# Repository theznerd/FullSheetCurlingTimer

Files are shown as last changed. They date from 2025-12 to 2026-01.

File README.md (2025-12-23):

# 🥌🥌🥌 Full Sheet Curling Timer 🥌🥌🥌

The purpose of this repository is to explore an inexpensive, ESP32-based, laser
trip timer for full sheet timing (4 lasers, 2 at each back line and 2 at each
hog line). Access to the times recorded by the timer is provided via a simple
web interface that connects to an ESP32 using the Web Bluetooth API. One ESP32
acts as a BLE Peripheral that hosts a custom GATT service for the timer, and all
four ESP32 devices will act as event detectors (laser trip detection) which
communicate the event data via ESP-NOW protocol to be picked up by the BLE
peripheral.

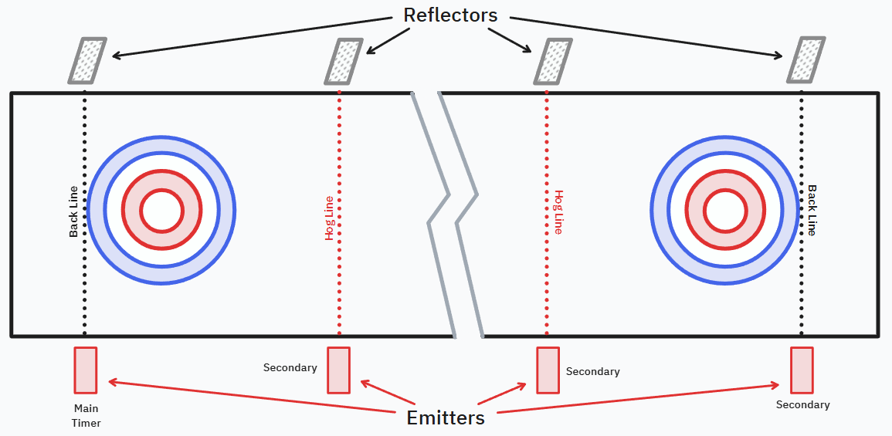
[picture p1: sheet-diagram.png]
Top-down view of sheet with emitters and reflectors


## License

This project is licensed under the Business Source License 1.1 (BUSL).
You may use it freely for noncommercial purposes.
For commercial use, please contact [nathan@z-nerd.com](mailto:nathan@z-nerd.com)
to obtain a commercial license.

## Goals

- **💸 Low-cost hardware**: inexpensive components (e.g., ESP32, laser modules)
  to keep single sheet cost under $150 (less when building for multiple sheets).
- **✅ Easy fabrication**: 3D-printable enclosure and PCBs for hobbyist skill
  level assembly (or schematics for breadboard assembly).
- **⏱️ Accurate timing**: millisecond-level accuracy for splits.
- **⚙️ Easy Setup and Use**: non-technical friendly setup and operation with
  guidance for setup and calibration provided in the web UI.
- **👀 Full sheet support**: support dual split timing (back line to hog line,
  and hog line to hog line) and bi-directional throws without moving hardware.
- **👨‍👩‍👧‍👦 Multi-viewer support**: allow multiple phones/tablets to connect and view
  timing data simultaneously.
- **🌐 Native App**: simple native app accessible from any modern platform
  with Bluetooth support - no cloud services, no complicated Wi-Fi setup for
  devices.

## Architecture (Multi-viewer)

### Roles and data flow

- **Main Timer and Laser Sensor - ESP32 = BLE Peripheral (GATT Server)**
  - Advertises a custom "Timer Service" so clients can discover it.
  - Has an assigned sheet ID (via dip switches) for identification.
  - Has an assigned placement ID (via dip switches) for sheet position.
  - Receives laser trip events from self and secondary timer devices (ESP-NOW).
  - Hosts characteristics for state + events.
  - Pushes timing updates using **notifications**.

- **Secondary Timer Devices - ESP32s = ESP-NOW Sender**
  - Has an assigned sheet ID (via dip switches) for identification.
  - Has an assigned placement ID (via dip switches) for sheet position.
  - Communicates laser trip events via ESP-NOW protocol.

- **Viewer (browser/web UI) = BLE Central (GATT Client)**
  - Scans for timer devices (filtered by name/service UUID).
  - Connects to **one** timer device at a time.
  - Provides diagnostics and setup UI.
  - Reads current timer state upon connection.
  - Subscribes to notifications to receive live updates.

This pattern supports multiple viewers concurrently: each viewer connects and
enables notifications independently.

### BLE Advertising For Viewer Discovery

To make it easy to pick the right timer when multiple devices are nearby, each
device should include clear identity in advertising:

- **Device name**: e.g., `CurlTimer Sheet 3`
- **Advertised Service UUID**: `Timer Service` (custom UUID)
- **Optional service/manufacturer data**: e.g., `sheetId`, `deviceId`,
  `firmwareVersion`

### GATT Service Model (proposed)

GATT is used for structured data exchange between the timer device and viewer.
GATT is well-suited for this use case due to its efficient notification
mechanism for real-time updates. Implementation details are discussed in the
[firmware design decisions](Firmware/design_decisions.md) document.

### Device-to-Device ESP-NOW Communication Model

ESP-NOW is the proposed protocol for communication between the laser sensors
and the main timer device. ESP-NOW was considered over BLE Advertising due to
better reliability and lower latency. Implementation details are discussed in
the [firmware design decisions](Firmware/design_decisions.md) document.

### Notes for future consideration

- WebKit has no support (actively opposes) for the Web Bluetooth API, and all
  iOS browsers are forced to use WebKit (with the exception of EU member
  states). Therefore, iOS support is not feasible with the current Web Bluetooth
  API limitations. Need to switch to a native app, which will bring added
  complexity. Looking at Avalonia for cross-platform native app development.
- It is possible to infer the direction of travel from the sequence of laser
  trip events, so that a stone passing the opposing back line does not cause a
  new timing event. However, this may be error-prone if stones are being thrown
  closely together in timing in opposite directions. Explicit direction setting
  from the viewer may be more reliable but requires user interaction which may
  be inconvenient or undesirable during practice.
- It may be useful to calculate the rock speed at each trip point and include
  that in the event data sent to viewers.
- **Timing accuracy note**: ESP-NOW retries/bursts improve delivery reliability
  but can add variable *arrival latency*. To keep recorded split times accurate,
  trip events should include a **sender-side capture timestamp** (taken at the
  instant the beam transition is detected), and the main timer should map that
  to its own clock using a lightweight beacon-based offset estimate.

## Wish List

- [ ] Apple WatchOS App for on-ice timing
- [ ] Garmin Connect IQ App for on-ice timing

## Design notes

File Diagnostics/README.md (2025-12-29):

# Diagnostic Tools

## Bluetooth LE

[BLE Scout](https://github.com/eriklins/BLE-Scout)

Works okay for basic scanning, but has a bug where the screen flashes and button
clicking is tempermental when scanning is active. Allowed me to see the
advertised names and services of the devices as well as connect and read the
GATT services and characteristics.

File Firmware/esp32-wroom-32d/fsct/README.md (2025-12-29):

# Full Sheet Curling Timer Firmware

Firmware for the Full Sheet Curling Timer project.

## Overview

This project implements embedded firmware for timing curling sheet events using
the an ESP32 microcontroller on a development board.

## Tested Hardware

- **ESP32-WROOM-32D Development Board**: Generic ESP32 dev board with the
    ESP32-WROOM-32D module.

## Build System

- **CMake**: Cross-platform build configuration
- **ESP-IDF**: Espressif IoT Development Framework

## Project Structure

```text
fsct/
├── main/              # Application source code
│   ├── adc/           # ADC driver implementation
│   ├── gatt/          # Bluetooth GATT service definitions
│   └── gpio/          # GPIO configuration
├── include/           # Header files
├── .devcontainer/     # Docker development environment
├── .vscode/           # VS Code configuration
└── build/             # Build artifacts (generated - excluded from repo)
```

## Getting Started

Use whatever you want - I don't care. I'm using VSCode with the ESP-IDF
extension, and I've installed v5.5.1 of the ESP-IDF toolkit. I don't use any of
the python scripts directly - I point an click in the ESP-IDF explorer to build,
flash, and monitor.

### Prerequisites

- ESP-IDF toolkit (v5.5.1 tested)

### Development Setup

Use the included Dev Container:

```bash
docker-compose up -d
```

Or configure manually with ESP-IDF.

### Building

```bash
idf.py build
```

### Flashing

```bash
idf.py flash
```

## Configuration

Edit `sdkconfig` or use the menuconfig tool:

```bash
idf.py menuconfig
```

## Version

See `version.txt` for current firmware version.

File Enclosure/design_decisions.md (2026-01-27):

# Enclosure Design Decisions

This document outlines the design decisions made for the enclosure of the trip
sensor for the project. The enclosure is designed to house the laser emitter,
phototransistor receiver, and associated component electronics providing
protection and proper alignment for accurate operation.

## Design Considerations

- **Durability**: The enclosure must be robust enough to withstand the
  environment of a curling sheet, including potential impacts and moisture.
- **Alignment**: The design must ensure precise alignment of the laser and
  phototransistor for accurate detection.
- **Ease of Assembly**: The enclosure should be easy to assemble and disassemble
  for maintenance and adjustments (e.g. where soldering is required, only use
  through-hole components).
- **Accuracy**: The enclosure must minimize external light interference to
  ensure reliable operation of the phototransistor (e.g. light tunneling).

## Current Needs Before Design

- [x] **PCB Design**: Finalize the PCB design to determine exact mounting points
  and dimensions for the enclosure.
- [x] **Component Dimensions**: Verify the dimensions of all components for
  accurate enclosure design.

## Current Notes from Field Tests

- Might better to put battery on top. Laser is a touch high of the midpoint
  of the stone.
  - Still considering this change which would allow for an adjustable base. The
    adjustable base would allow for fine tuning the height and angle of the
    laser, especially if a sheet is not level.
- ~~Laser alignment is very tempermental. Recommend decreasing tunnel diameter and hot gluing after aligned.~~
  - ~~Laser alignment is tempermental, but decreasing tunnel diameter did not yield
    better results (it forced the laser to be pointed possiby off axis without a
    way to adjust). Going back to a larger tunnel diameter and using hot glue to
    fix the laser in place after alignment.~~
  - Laser alignment is still an issue. Going to flip the laser module to the
    bottom of the enclosure, and then add a small ball joint mount to allow for
    fine tuning the laser angle when placing on the ice.

## Involved Components

### Laser Diode Module

The laser diode module used is a standard 650nm red laser module, with an 6mm OD
housing that includes a small notch in the middle for placement. A small circuit
board is attached to the back of the laser module that includes a resistor for
current limiting and a positive and ground wire.

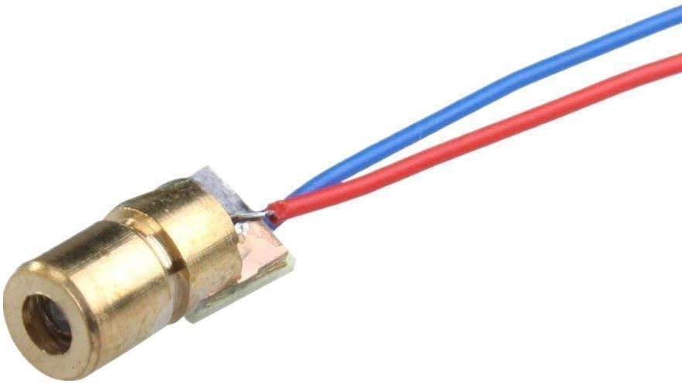
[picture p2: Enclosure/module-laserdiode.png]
Laser Diode Module


> NOTE: The reflector design was initially based on retroreflective tape, but
> this was found to be unreliable at distances beyond 1-2 meters. The design has
> been updated to use small bicycle retroreflectors for improved reliability.
> Still need to field test this change - especially with bright overhead
> lighting and reflective ice surfaces. An initial test of some rectangular
> reflectors was unreliable at 3-4 meters, but a standard bicycle reflector
> performed much more reliably.

### Main PCB Module

The main PCB module houses the main circuitry for the project. The PCB is
designed to fit within the enclosure and provide connections for ESP32 dev
board, power, laser, and phototransistor. The PCB is also designed to align the
phototransistor with the enclosure opening for optimal light detection and ease
of alignment. A 5-position DIP switch is included on the PCB for sheet and
placement ID selection, but does need to be externally accessible as the values
are not changed frequently.

\#\#\# No Photo Available Yet

### Piezo Buzzer Module

The piezo buzzer module is used to provide audio feedback for user interactions
such as power on/off and timing events. The buzzer is mounted on the main PCB
and positioned within the enclosure to allow sound to escape effectively. The
buzzer is an active type, meaning it includes an internal oscillator and only
requires a DC voltage to operate.

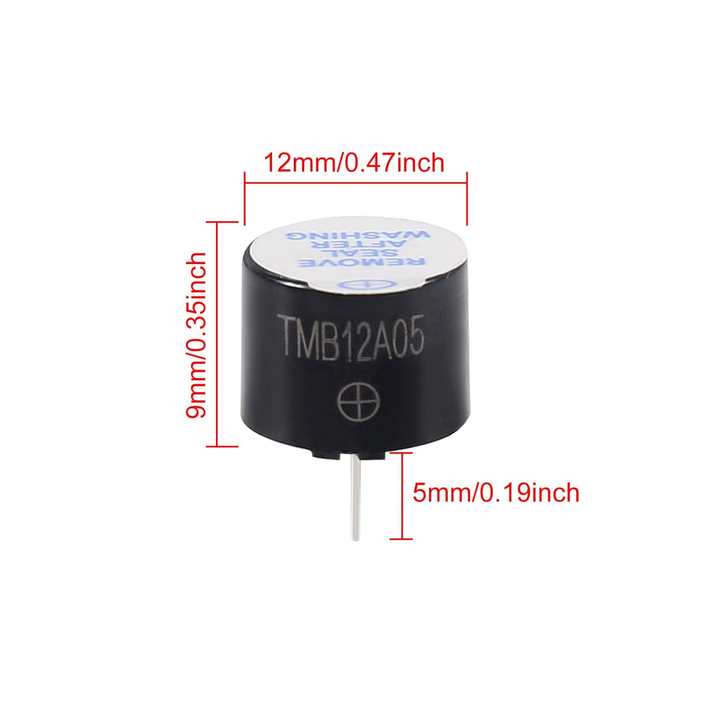
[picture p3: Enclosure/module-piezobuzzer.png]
Piezo Buzzer Module


### TP4056 Battery Charger Module with 5V Step-Up

The TP4056 battery charger module is used to charge the 18650 Li-ion battery. It
is mounted separately from the main PCB to allow for use of a development board
instead of integrating the charger and associated SMD components into the main
PCB (keeping the project hobbyist friendly). It has a USB-C connector for easy
charging. The module also includes LED indicators for charging status. It has an
integrated step-up converter to provide a regulated 5V output for the ESP32 dev
board and other components.

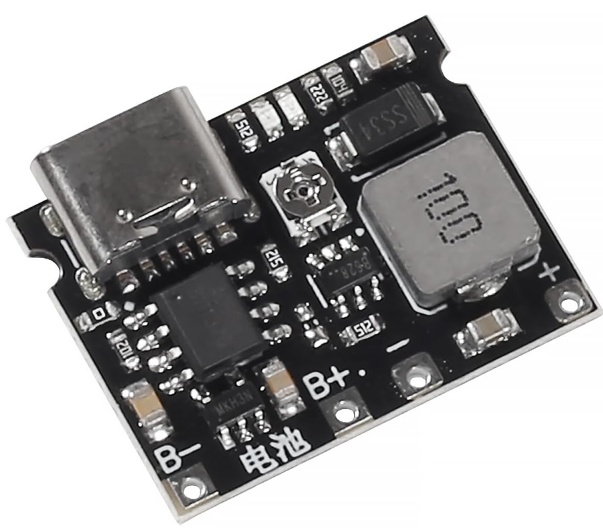
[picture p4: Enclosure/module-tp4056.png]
TP4056 Battery Charger Module


### 18650 Battery Holder

The 18650 battery holder is used to securely hold the battery within the
enclosure. It includes leads for easy connection to the main PCB.

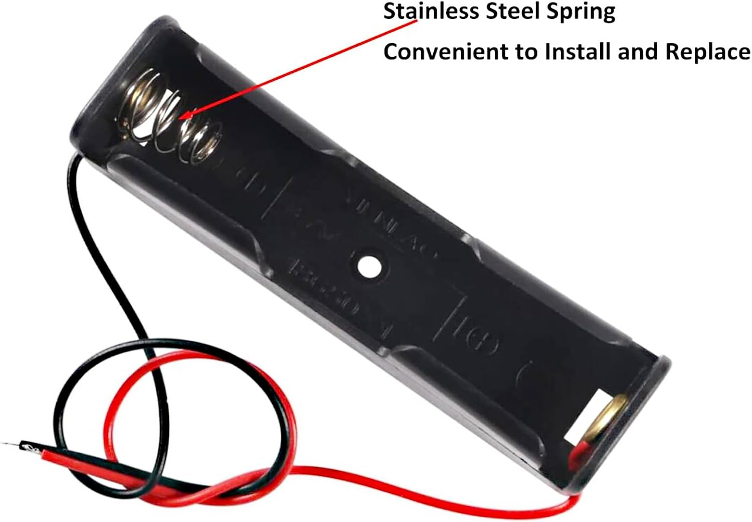
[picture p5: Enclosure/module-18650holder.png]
18650 Battery Holder


### Rocker Switch

The rocker switch is used to control power to the device. It is mounted on the
enclosure for easy access and large enough to operate while wearing thin gloves.

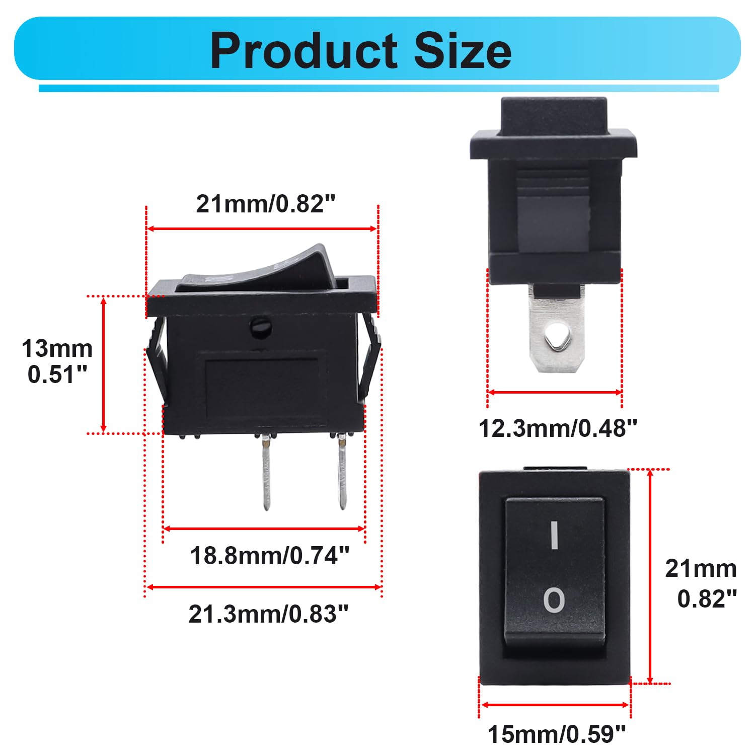
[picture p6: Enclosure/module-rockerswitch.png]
Rocker Switch


### External Antenna

An external 2.4GHz antenna is used to improve the wireless range of the ESP32
dev board. The antenna is connected via an IPEX connector on the ESP32 board and
is mounted externally to the enclosure for optimal signal reception.

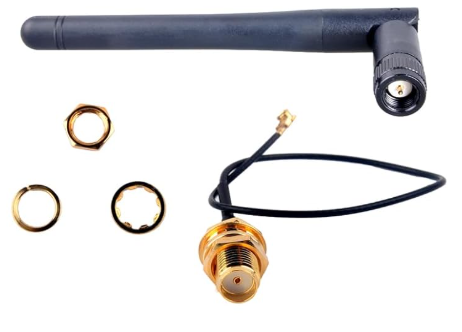
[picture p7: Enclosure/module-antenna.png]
External Antenna


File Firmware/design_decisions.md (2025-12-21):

# Firmware Design Decisions

This document outlines the design decisions made for the firmware of the trip
sensor for the Full Sheet Curling Timer project.

## Firmware Architecture

- **Single Firmware Image**: A single firmware image is used for both the main
  timer device (BLE Peripheral) and the secondary timer devices (ESP-NOW
  Senders), with behavior determined at runtime based on DIP switch settings.
- **Development Board Target**: The firmware is designed to run on ESP32
  development boards to keep the project hobbyist friendly and avoid the need
  for custom PCB designs for the microcontroller.

## Wireless Communication

### ESP-NOW

The ESP-NOW protocol is used for low-latency, connectionless communication
between the secondary timer devices and the main timer device. This allows for
quick transmission of laser trip events without the overhead of traditional
Wi-Fi connections and higher reliability than BLE advertising alone.

#### ESP-NOW Provisioning

Provisioning is designed to require **no MAC address entry** and no external
app. All devices are configured only via DIP switches and then automatically
discover and associate at boot.

- **DIP switch identity**
  - `sheetId` (3 bits): identifies the sheet (supports up to 8 sheets).
  - `locationId` (2 bits): identifies placement/role.
    - `00` = **Main Timer** (ESP-NOW receiver/aggregator)
    - `01`–`11` = **Secondary Sensors** (ESP-NOW transmitters)
- **Boot-time discovery (same firmware image)**
  - All devices initialize ESP-NOW on a fixed, predefined Wi-Fi channel.
  - **Main Timer (`locationId=00`)** periodically broadcasts a short
    `MAIN_BEACON` containing at minimum `{sheetId, mainMac, epoch}`.
  - **Secondary sensor (`locationId!=00`)** listens for a matching
    `MAIN_BEACON` (same `sheetId`), then caches `mainMac` and sends a
    `SENSOR_JOIN` message containing `{sheetId, locationId, sensorMac, epoch}`.
  - The Main Timer records `(locationId -> sensorMac)` and may optionally reply
    with a unicast `JOIN_ACK` so the sensor can confirm it is paired to the
    correct Main Timer.
- **Conflict handling**
  - If two devices present the same `(sheetId, locationId)`, the Main Timer
    treats this as a configuration error (DIP collision) and should reject or
    flag the duplicate sender.
- **Persistence**
  - Learned MACs will be cached in RAM for the session but will not be stored in
    non-volatile storage to speed reconnection after reboot for simplicity and
    ease of replacement should devices be swapped out.

#### Message format (minimal, fixed-size)

ESP-NOW payloads are kept small, fixed-size, and binary to minimize airtime and
parsing overhead. All messages begin with a common header so receivers can
quickly filter by `sheetId` and `msgType`.

- **Common header (all messages)**
  - `uint8_t  version` (start at `1`)
  - `uint8_t  msgType` (enum below)
  - `uint8_t  sheetId` (0-7)
  - `uint8_t  locationId` (0-3; `0` = main, `1-3` = sensors)
  - `uint16_t epoch` (per-boot *session id* used to prevent `eventId` collisions
    after reboot; generated randomly at boot by default)
  - `uint16_t crc16` (CRC of the message excluding the crc field)

- **Message types**
  - `MAIN_BEACON` (broadcast)
    - `uint8_t  mainMac[6]`
    - `uint8_t  channel` (ESP-NOW channel in use)
    - `uint32_t mainTimeUs32` (Main Timer local timebase, e.g.,
      `esp_timer_get_time()` truncated)
  - `SENSOR_JOIN` (broadcast or unicast to `mainMac`)
    - `uint8_t sensorMac[6]`
  - `JOIN_ACK` (unicast)
    - `uint8_t mainMac[6]`
    - `uint8_t accepted` (0/1)
  - `TRIP_EVENT` (unicast)
    - `uint32_t eventId` (monotonic per sensor per epoch)
    - `uint8_t  eventCode` (beam broken/restored, etc.)
    - `uint32_t sensorTimeUs32` (**timestamp captured at detection time** on the
      sender)

Notes:

- `epoch` exists so that if a device reboots and its `eventId` counter restarts,
  the Main Timer can still distinguish "new events after reboot" from delayed or
  duplicated packets from the prior session.
- CRC is optional but strongly recommended to avoid false triggers from corrupt
  frames in a noisy RF environment.
- If the Main Timer derives "event time" from *packet arrival*, then any
  retry/burst spacing (and RF contention) directly becomes timestamp error. To
  avoid that, **timestamp at the sensor** and transmit the capture time in
  `TRIP_EVENT`. The Main Timer can then map `sensorTimeUs32` into its own
  timebase using the most recent `MAIN_BEACON` time correlation.

#### Timing and retry policy (8-sheet environment)

The goal is fast join and high reliability without excessive airtime when many
sheets are active.

- **ESP-NOW channel**
  - Use a fixed channel for all devices (e.g., channel `1`, `6`, or `11`).
  - Transmit the channel in `MAIN_BEACON` for diagnostics.

- **Join window (boot-time discovery)**
  - On boot, all devices run a discovery window of **10 seconds**.
  - The Main Timer continues to beacon at a low rate after the window so late
    sensors can still join.

- **Main beacon interval**
  - During discovery window: **250 ms** interval (fast association).
  - After discovery window: **2 s** interval (low background airtime).

- **Sensor join attempts**
  - After receiving a matching `MAIN_BEACON`, a sensor sends `SENSOR_JOIN` and
    waits for `JOIN_ACK`.
  - Retry `SENSOR_JOIN` up to **5 times** with randomized backoff:
    - base delay **150 ms** + random jitter **0-150 ms**.
  - If no ack arrives after retries, fall back to listening for beacons and
    repeat.

- **Trip event delivery (recommended)**
  - Use **unicast** to `mainMac` once learned.
  - On each laser trip, send a short burst to mitigate collisions/interference:
    - **3 transmissions** total per event
    - spacing: **25 ms** + random jitter **0-20 ms**
  - Main Timer dedupes by `(sheetId, locationId, epoch, eventId)`.
  - **Important**: the burst spacing should not affect the *recorded* time when
    `sensorTimeUs32` is used as the source-of-truth timestamp. The spacing only
    affects how quickly the Main Timer *learns* about the event, not when the
    event is considered to have occurred.

- **Timebase alignment (recommended for accurate splits)**
  - Each `MAIN_BEACON` includes `mainTimeUs32`.
  - Each sensor records `(mainTimeUs32, sensorLocalTimeUs32_at_beacon_rx)` for
    the latest beacon(s) and maintains an estimated offset:
    - `offsetUs ~= mainTimeUs32 - sensorTimeUs32_at_beacon_rx`
  - When sending `TRIP_EVENT`, the Main Timer can estimate:
    - `eventMainTimeUs ~= sensorTimeUs32 + offsetUs`
  - This keeps “registered time” decoupled from RF retries and burst jitter,
    with residual error dominated by beacon receive latency and clock drift
    (typically far smaller than 25–90 ms).

### Bluetooth Low Energy (BLE) - GATT Server

The main timer device acts as a BLE GATT server, advertising a custom "Timer
Service" for viewer devices (browsers) to connect to and receive timing updates
via notifications. The GATT Server should host a small set of characteristics:

- **Timer Events** (`Notify`)
  - Streams *incremental* one-way event updates (laser trips, split times,
    rock speed, etc.).
  - Viewers subscribe once; Main Timer ESP32 pushes updates when they occur.
  - Events should include a monotonically increasing sequence number so clients
    can detect gaps.

- **Timer State** (`Read` + `Notify`)
  - A bounded *snapshot* of the current timer state (idle/running/finished),
    direction, current/last time, etc.
  - Includes **recent history** (e.g., up to **N** most recent recorded times)
    so late-joining/reconnected viewers can render immediately.
  - Keep this payload compact and capped (fixed max N) so it remains fast to
    read/notify.

- **Control** (`Write`, optional)
  - Commands from a viewer to the ESP32 (e.g., `reset`, `delete last time`,
    `set direction`).

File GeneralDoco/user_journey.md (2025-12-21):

# User Journeys and Use Cases

This document holds considerations for how users will interact with the curling
timer system, including setup, operation, and maintenance. This document should
be used to guide design decisions in firmware, enclosure, and overall system
architecture.

## Preconfiguration

### Device Identification

The devices have a 5-position DIP switch for configuration of identity. The
first 3 positions set the `groupId` (0-7) to identify which group the device
belongs to (could be used as a sheet number). The last 2 positions set the
`deviceId` (0-3) to identify the role/placement of the device within the group:

- `00` = **Main Timer** (ESP-NOW receiver/aggregator and BLE peripheral)
- `01` = **Sensor 1 - Nearest Hog Line** (ESP-NOW transmitter)
- `10` = **Sensor 2 - Opposing Hog Line** (ESP-NOW transmitter)
- `11` = **Sensor 3 - Opposing Back Line** (ESP-NOW transmitter)

A group of four devices (one main timer and three sensors) should be configured
with the same `groupId` and unique `deviceId`s to form a complete set for one
sheet.

## Setup Journeys

### Charging

Charging is handled via TP4056 modules with USB-C input. Users should be able to
easily connect a USB-C cable to each device for charging. Two LED indicators on
the module show charging status (red = charging, green = charged [NOTE: NEEDS
CONFIRMATION OF COLORS]). The TP4056 modules include overcharge protection, so
users can leave devices connected without risk of damage.

### Power On/Off

Each device includes a rocker switch for power control. Users should toggle the
switch to the "on" position to power on the device. There is no LED indicator
for power status, but the device will emit a short beep from the piezo buzzer
upon power on to indicate it is active.

All devices in a group should be powered on within 30 seconds of each other to
ensure proper ESP-NOW pairing and synchronization. The order of powering on the
devices should be designed to not matter. If the (non-main sensors) are not
powered on within 30 seconds of the main timer, it may take longer for pairing
to complete.

### Placement and Alignment

Users should place the devices at their designated locations down the sheet.
Room should be left behind each device for a curler to come around without
tripping the laser beam when returning from delivering a stone. On the opposite
side of the sheet from the device, the reflecting hardware (retroreflective tape
applied to a 3d printed mount) should be placed to reflect the laser beam back
to the phototransistor in the device.

- **Main Timer (Device ID: 00)**: Positioned on the back line
- **Sensor 1 (Device ID: 01)**: Positioned on the near hog line
- **Sensor 2 (Device ID: 10)**: Positioned on the far hog line
- **Sensor 3 (Device ID: 11)**: Positioned on the far back line

### Connection to Viewer

Users should connect to the main timer device using the provided native app,
This app will guide users through scanning for nearby timer devices, selecting
the correct one based on advertised name, and connecting to it. Once connected,
the native app will display the current timer state and provide controls for
validating the orientation/alignment of the laser sensors and retroreflectors.

## Operation Journeys

### Recording a Delivery

The user starts a timer by delivering a stone. When the stone crosses the laser
on either back lines, the main timer device records the start time and begins
timing (there are two timer threads to account for both directions, should an
accidental trip occur either because of throwing the stone through the house or
another curler crossing the beam). Upon crossing the back line laser, a
debounce period of one second is initiated to prevent multiple trips from being
recorded in quick succession and the initial trip of the back line laser sends
an arming signal to the hog line sensors. Based on which hog line sensor is
tripped next, the main timer records the split time from the appropriate back
line sensor (for back line to hog line split). When the stone crosses the
opposite hog line laser, the hog-to-hog split time is recorded. Each sensor
crossing event inclues a short beep from the piezo buzzer to provide audio
feedback to the curler that the trip was registered. Additionally, the sensors
record the laser break and restore times to provide a general speed of the
stone. This should allow the curler to get a rough idea of whether they are
positive or negative on their throw speed and by how much.

### Viewing Results

The native app connected to the main timer device will display timing results in
real-time as the stone crosses each laser sensor. The UI will show the split
times for back line to hog line and hog line to hog line, as well as the
approximate stone speed based on laser break and restore times. The UI will
also provide visual indicators for each sensor trip event and any errors or
issues encountered during timing.

### Resetting the Timer

In the event of a false start, accidental trips, or if the stone does not cross
the opposing hog line, the user can reset the timer via the native app. If the
user prefers to wait, a new delivery can be started by simply crossing the back
line laser again after the debounce period has elapsed. Partial times will still
be available in the native app for review, but can be cleared from the native
app if desired.

## Maintenance Journeys

### Battery Charge Monitoring

The native app can provide a battery charge status indicator based on voltage
readings from an adc pin on the ESP32 connected to the battery voltage divider.
The voltage divider solution is not highly accurate, but should provide a rough
indication of battery health. Users can monitor this status in the native app
and be alerted when the battery charge is low and needs recharging.

### Battery Replacement

The devices use a single 18650 Li-ion battery for power. When the battery
reaches end-of-life or fails to hold a charge, users should be able to easily
replace the battery. The enclosure is designed to come apart with a few screws,
allowing access to the battery holder. Users can remove the old battery and
insert a new 18650 battery, ensuring correct polarity. The enclosure can then
be reassembled and the device powered on for use.

### Firmware Updates

At least initially, firmware updates will require connecting the ESP32 dev board
to a computer via USB and using the Arduino IDE or ESP32 flashing tools to
upload new firmware. As these devices are hobbyist-focused, users with some
technical knowledge should be able to perform firmware updates as needed. In
the future, over-the-air (OTA) updates could be considered to simplify this
process.

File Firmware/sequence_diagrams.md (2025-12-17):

# Firmware Sequence Diagrams

## Timer Event Flow

```mermaid
sequenceDiagram
  participant BL1 as Main Back Line Sensor (ESP32)
  participant H1  as Close Hog Line Sensor (ESP32)
  participant H2  as Far Hog Line Sensor (ESP32)
  participant BL2 as Far Back Line Sensor (ESP32)

  Note over BL1,BL2: Any trip of the back line sensors outside of the debounce period should reset and start the internal timer for the Main Back Line Sensor and send an "ARM_TIMER" command to both hog line sensors.

  alt Main Back Line Sensor detects laser trip
    BL1->>BL1: reset and start internal timer
    BL1->>BL2: Send "DEBOUNCE" command via ESP-NOW
  else Far Back Line Sensor detects laser trip
    BL2->>BL1: Send "TRIP_EVENT" to Main Timer via ESP-NOW
  end

  BL1->>BL1: Ignore further trips for 3000ms (debounce)
  BL2->>BL2: Ignore further trips for 3000ms (debounce)
  BL1->>BL1: reset and start internal timer
  BL1->>H1: Send "ARM_TIMER" command via ESP-NOW
  BL1->>H2: Send "ARM_TIMER" command via ESP-NOW
  BL1->>BL1: Ignore further trips for 3000ms (debounce)

  alt H1 detects laser trip while armed
    H1->>BL1: Send "TRIP_EVENT" to Main Timer via ESP-NOW (trip time)
    H1->>H1: Wait for laser to clear
    H1->>BL1: Send "TRIP_EVENT" to Main Timer via ESP-NOW (stone speed)
    BL1->>BL1: Broadcast "TIMER EVENT" via BLE GATT Notifications to Viewers
  else H1 detects laser trip while unarmed
    H1->>H1: Ignore trip
  end

  alt H2 detects laser trip while armed
    H2->>BL1: Send "TRIP_EVENT" to Main Timer via ESP-NOW (trip time)
    H2->>H2: Wait for laser to clear
    H2->>BL1: Send "TRIP_EVENT" to Main Timer via ESP-NOW (stone speed)
    BL1->>BL1: Broadcast "TIMER EVENT" via BLE GATT Notifications to Viewers
  else H2 detects laser trip while unarmed
    H2->>H2: Ignore trip
  end
```

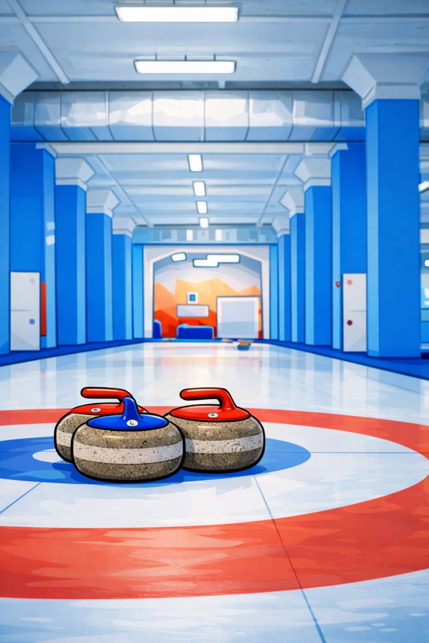
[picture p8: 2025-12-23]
Mobile/FSCT.Mobile/FSCT.Mobile/Assets/Background.png

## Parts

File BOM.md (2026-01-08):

# Bill of Materials

**STATUS:** INITIAL DRAFT - DO NOT USE FOR PROCUREMENT

**VERSION:** 0.3

**LAST UPDATED:** 2026-01-06
This document lists the components required to build the Full Sheet Curling
Timer for a single sheet.

## Electronic and Mechanical Components

| Component | Quantity | Description | Link | Price (each) | Total Price | Notes |
| --- | --- | --- | ---- | --- | --- | ----- |
| ESP32 Dev Board with IPEX Connector | 4 | ESP32-WROOM-32 or similar | [Amazon](https://www.amazon.com/dp/B0865YSHSS) | $5.50 | $22.00 | Ensure it has an IPEX connector for external antenna |
| 2.4GHz Antenna | 4 | WiFi antenna with U.FL to Female SMA cable | [Amazon](https://www.amazon.com/dp/B0CD7LBJ3D) | $3.00 | $12.00 | 3dBi gain recommended |
| 18650 Batteries | 4 | Rechargeable Li-ion batteries | [Amazon](https://www.amazon.com/dp/B0DF6CPJFR) | $5.75 | $23.00 | 3000mAh or higher |
| 18650 Battery Holders | 4 | Single 18650 battery holder with leads | [Amazon](https://www.amazon.com/dp/B00LSG5BKO) | $0.80 | $8.00 | Pack comes with 10 |
| 18650 Battery Charger Module | 4 | TP4056 charger module with protection and 5V step-up | [Amazon](https://www.amazon.com/dp/B0BJYRGZR4) | $1.00 | $10.00 | Pack comes with 10 |
| Laser Diode Module | 4 | 650nm red laser module | [Amazon](https://www.amazon.com/dp/B071FT9HSV) | $0.68 | $6.80 | Pack comes with 10 |
| 5MM Phototransistor | 4 | Light-sensitive phototransistor | [Amazon](https://www.amazon.com/dp/B00M1PMHO4) | $0.29 | $5.79 | Pack comes with 20 |
| LM393 Comparator | 4 | LM393-based light sensor module | [Amazon](https://www.amazon.com/dp/B0DK262285) | $0.40 | $8.00 | Pack comes with 20 |
| Various Resistors | N/A | Various resistors for voltage dividers and pull-ups | [Amazon](https://www.amazon.com/dp/B08FD1XVL6) | N/A | $10.00 | Pack comes with assorted values, and way too many. Will optimize later based on actual schematic needs. |
| Various Capacitors | N/A | Various capacitors for power smoothing | [Amazon](https://www.amazon.com/dp/B07PBQXQNQ) | N/A | $17.00 | Pack comes with assorted values, and way too many. Will optimize later based on actual schematic needs. |
| Rocker Switch | 4 | SPST rocker switch for power control | [Amazon](https://www.amazon.com/dp/B0CVTRKJTV) | $0.75 | $6.00 | Pack comes with 8 |
| Piezo Buzzer | 4 | Active piezo buzzer for audio feedback | [Amazon](https://www.amazon.com/dp/B0F1KCZGZG) | $0.40 | $8.00 | Pack comes with 20 |
| BC337 NPN Transistor | 4 | General purpose NPN transistor to drive Piezo | [Amazon](https://www.amazon.com/dp/B07T61SY9Y) | $0.04 | $9.00 | Pack comes with assorted transistors, and way too many. Will optimize later based on actual schematic needs. |
| Single Row Female Header Pins | 4 | 19-pin single row (1x19) | [Amazon](https://www.amazon.com/dp/B07CGGSDWF) | $0.17 | $10.00 | Pack comes with 60 pins |
| 5 position DIP Switch | 4 | 5-position DIP switch for ID configuration | [Amazon](https://www.amazon.com/dp/B082GMFTKZ) | $0.65 | $6.50 | Pack comes with 10 |
| Bicycle Front Reflector | 4 | Pack with front and back | [Amazon](https://www.amazon.com/dp/B0DF2Q8QSN) | $1.25 | $12.50 | Pack comes with 10 |

### Notes

- Retroreflective tape was attempted but found to be unreliable at distances
  beyond around 1-2 meters. The small rectangular reflectors provide a much more
  reliable reflection for the laser sensors.

For the resistors and capacitors, the BOM above includes many more than
actually needed. The actual required values are as follows if you can source
them individually:

| Component | Quantity | Value | Purpose |
| --- | --- | ----- | --- |
| Resistor | 8 | 10kΩ | LM393 Output and Phototransistor pull-up to 3.3v |
| Resistor | 12 | 100kΩ | LM393 1.65v reference divider, Battery ADC voltage divider |
| Resistor | 4 | 47kΩ | Battery ADC voltage divider |
| Resistor | 4 | 1MΩ | LM393 Hysteresis feedback |
| Resistor | 4 | 1kΩ | GPIO to BC337 current limiting |
| Capacitor | 8 | 0.1µF | LM393 Power supply decoupling and ESP32 GPIO noise suppression |

## PCB Fabrication

The design can be fabricated using a PCB manufacturing service. Below are the
estimated costs for a batch of 5 PCBs (give yourself some grace for mistakes).
It is recommended you take the PCB approach rather than breadboarding as the
enclosure models are designed to fit the PCB form factor and to properly align
the laser and phototransistor components.

| Service | Quantity | Price per PCB | Total Price | Notes |
| --- | --- | --- | --- | ----- |
| JLCPCB | 20 | $2.80 | $56.10 | Good coupons for new users, this was including fast shipping as well, price difference between 5 and 20 was negligible |
| OSHPark | 6 | $11.40 | $68.40 | US based, comes at higher cost |

## Sensor Enclosure and Reflector 3D Prints

The enclosures for the laser and phototransistor sensors, as well as the
retroreflector mounts, can be 3D printed. Below are estimated costs based on
material usage. ABS or PETG is recommended for durability, but PLA can be used
as well as it is generally more accessible for hobbyists (someone in your club
probably has a 3D printer they can lend to the effort).

| Material | Quantity | Price per kg | Estimated Usage (g) | Total Price | Notes |
|---|---|---|---|---|---|

\#\#\# TO BE DETERMINED

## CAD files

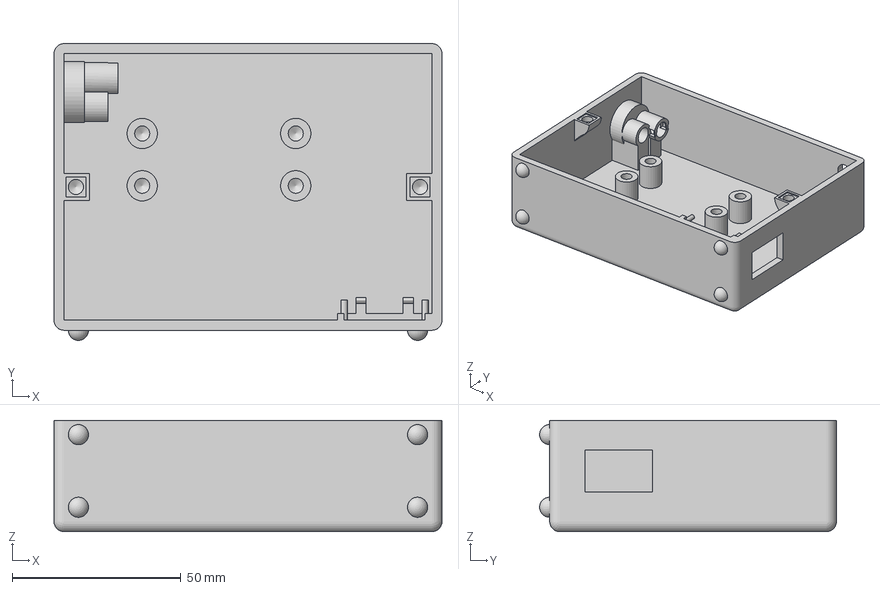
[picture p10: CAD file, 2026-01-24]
Enclosure/Curling Timer v1 - Main Body - Test 10.3mf
115.0 x 88.0 x 33.0 mm

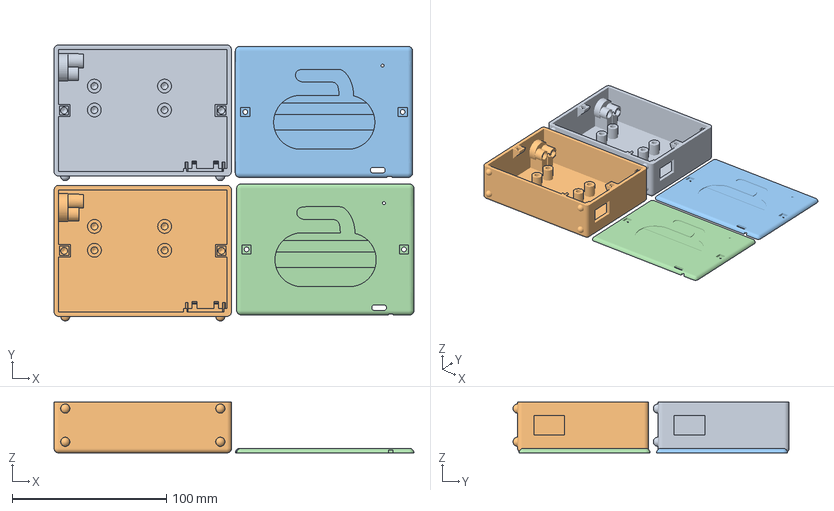
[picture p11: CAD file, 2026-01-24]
Enclosure/Curling Timer v1 - Main Body and Side Panel - Test.3mf
233.4 x 178.9 x 33.0 mm
Main Body x 2
Side Cover x 2

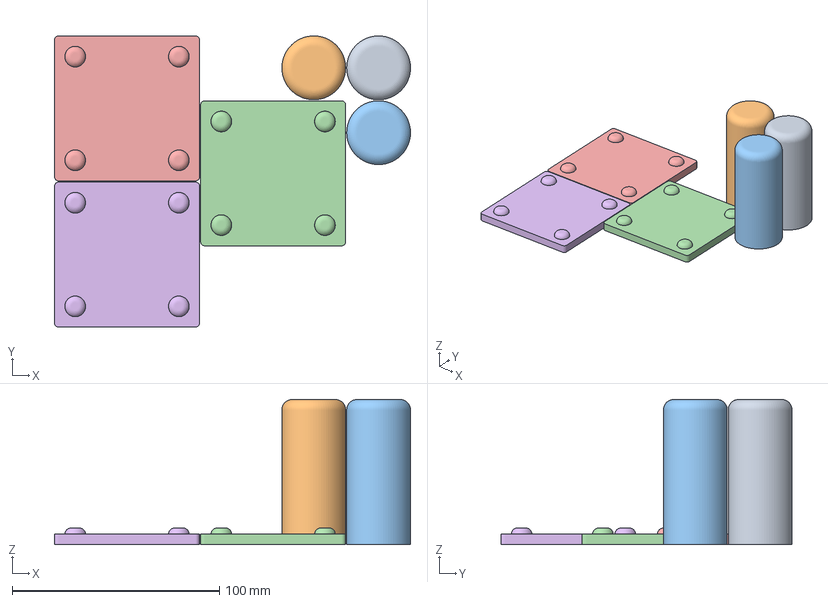
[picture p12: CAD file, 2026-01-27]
Enclosure/Reflector Mount Base.3mf
171.8 x 140.5 x 70.0 mm

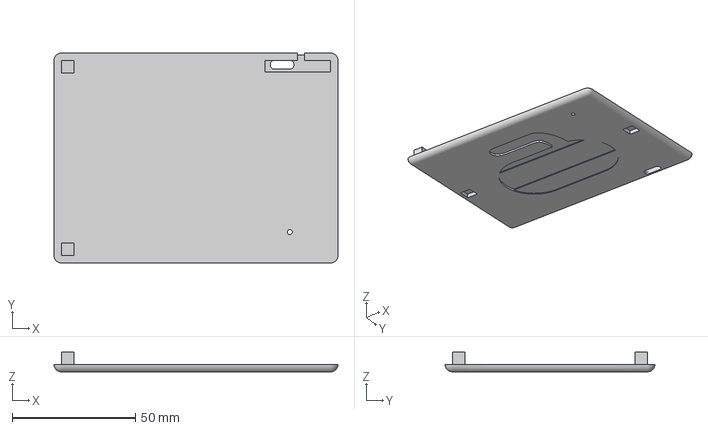
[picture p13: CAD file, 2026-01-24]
Enclosure/Curling Timer v1 - Side Cover Test 1.3mf
115.0 x 85.0 x 8.00 mm

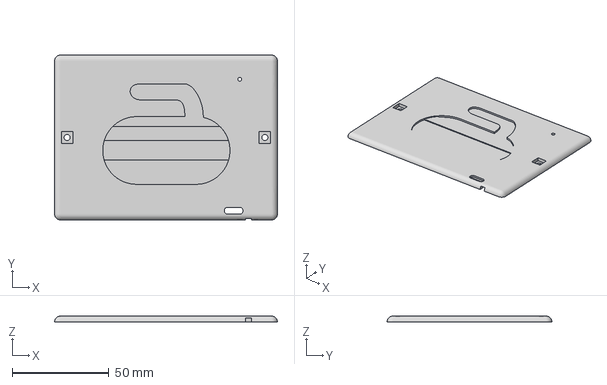
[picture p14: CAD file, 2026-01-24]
Enclosure/Curling Timer v1 - Side Cover - Test 2.3mf
115.0 x 85.0 x 3.00 mm

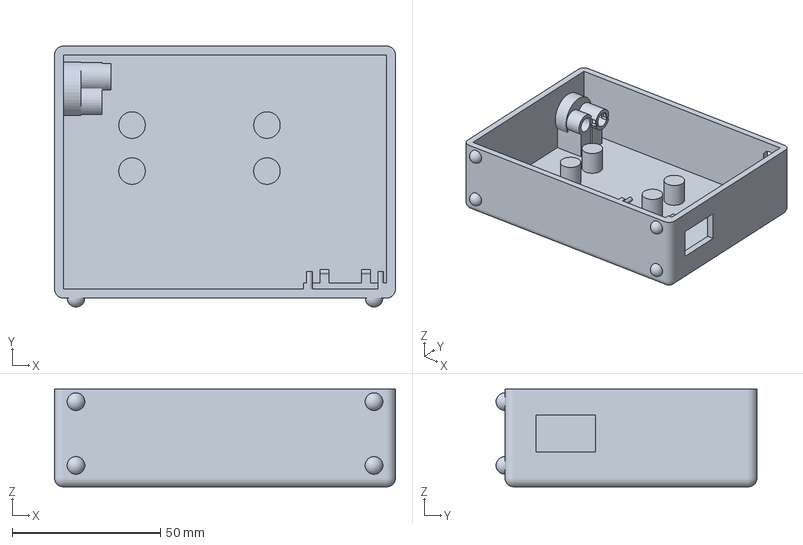
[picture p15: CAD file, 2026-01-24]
Enclosure/Curling Timer v1 - Test 6.3mf
115.0 x 88.0 x 33.0 mm

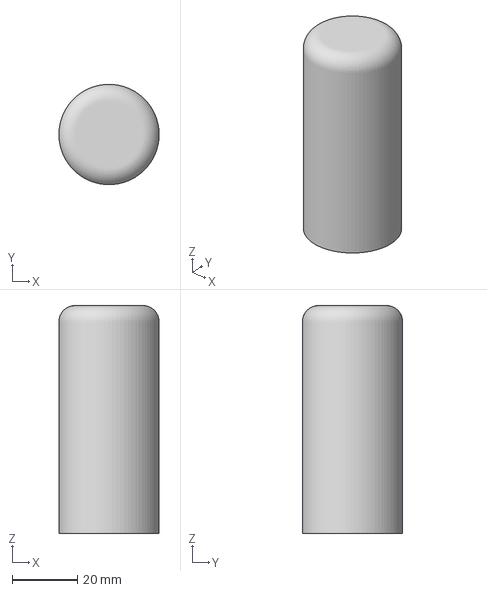
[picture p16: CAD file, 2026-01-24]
Enclosure/Reflector Mount Post.3mf
30.8 x 30.8 x 70.0 mm

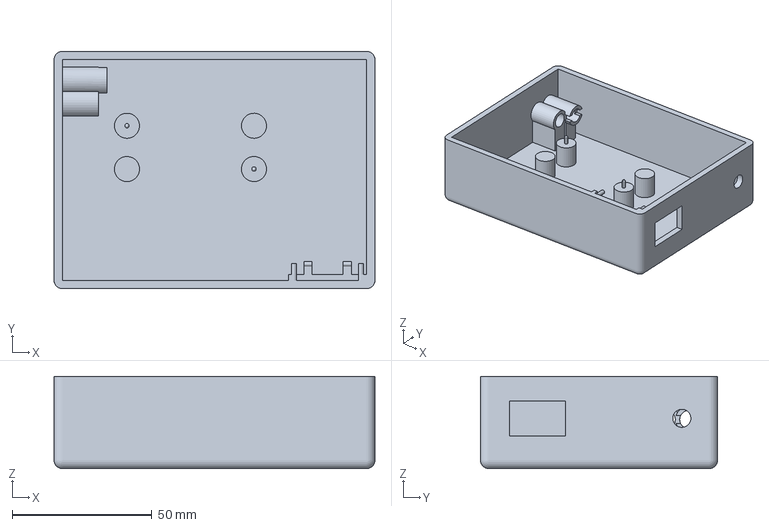
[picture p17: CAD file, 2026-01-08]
Enclosure/Curling Timer v1 - Test 3.3mf
115.0 x 85.0 x 33.0 mm

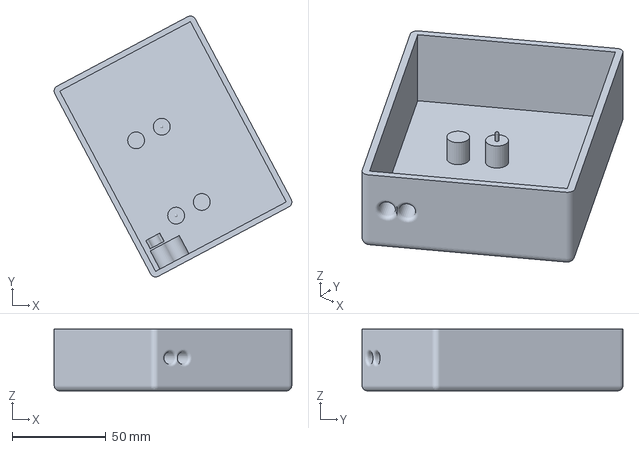
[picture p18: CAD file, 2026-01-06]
Enclosure/Curling Timer v1 - Test 2.3mf
126.9 x 139.3 x 33.0 mm

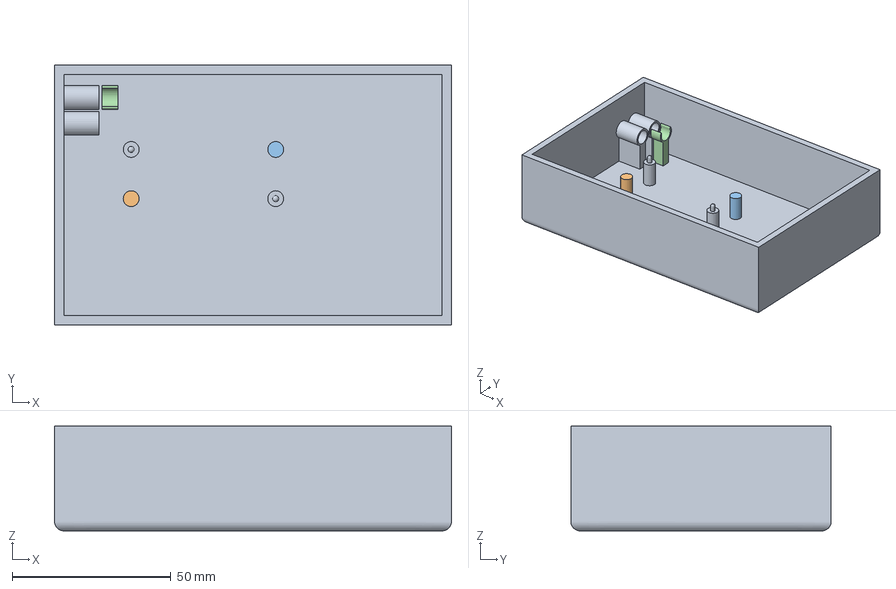
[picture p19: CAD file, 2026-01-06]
Enclosure/Curling Timer v1 - Test.3mf
125.0 x 82.0 x 33.0 mm

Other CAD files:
Enclosure/Curling Timer v1 - Main Body - Test 8.3mf
Enclosure/Curling Timer v1 - Main Body - Test 9.3mf
Enclosure/Curling Timer v1 - Test 7.3mf
Enclosure/Curling Timer v1 - Test 5.3mf
Enclosure/Curling Timer v1 - Test 4.3mf

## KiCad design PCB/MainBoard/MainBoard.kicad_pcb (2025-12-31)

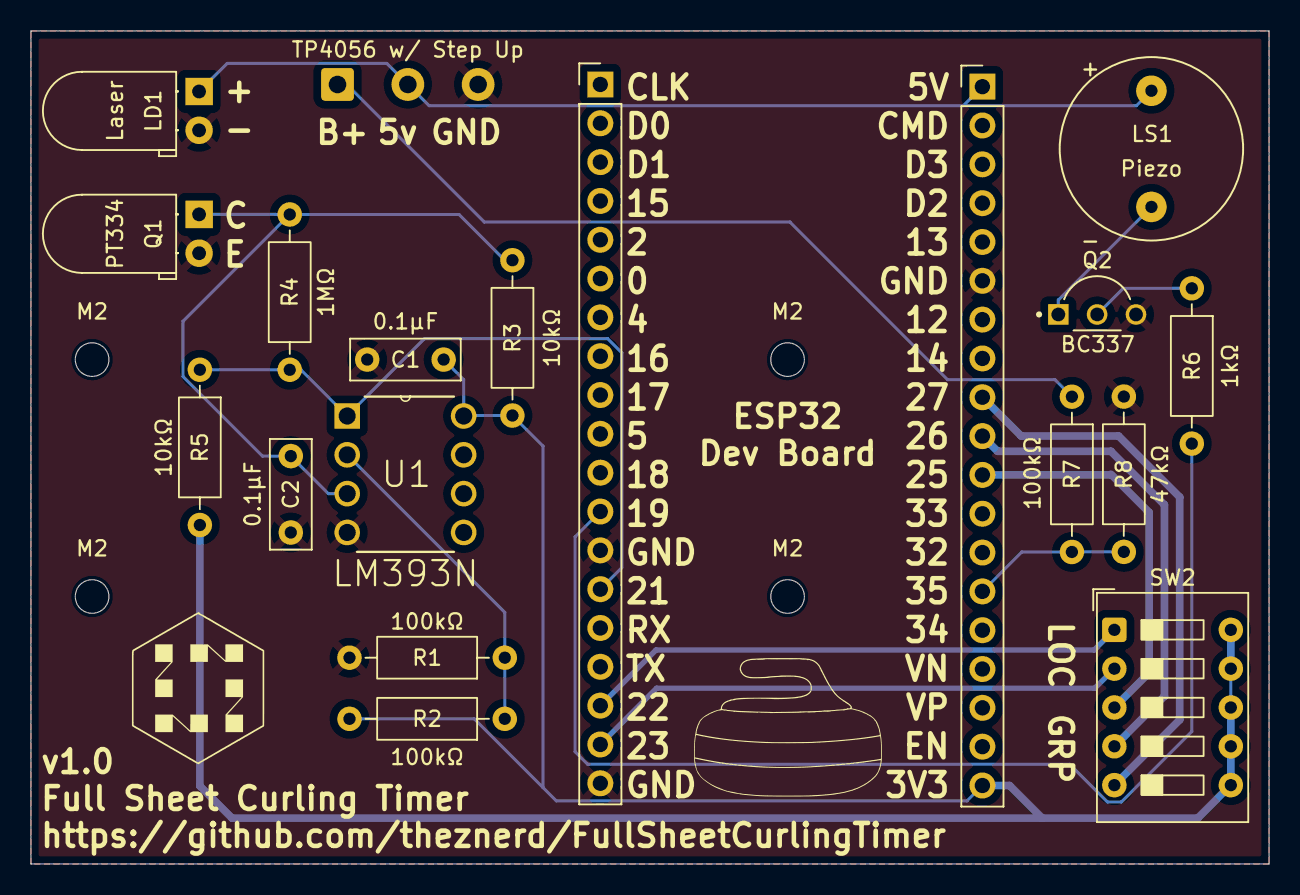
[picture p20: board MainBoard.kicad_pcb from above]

Board: 2 copper layers, 81.0 x 54.5 mm, 23 parts (0 on the bottom side), 16 nets.

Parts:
 : PinHeader_1x19_P2.54mm_Vertical
 #2: PinHeader_1x19_P2.54mm_Vertical
C1, C2: 0.1µF; C_Disc_D7.0mm_W2.5mm_P5.00mm
LD1: Laser; LED_D5.0mm_Horizontal_O1.27mm_Z3.0mm_Clear
LS1: Piezo; CUI_CMI-1295IC-0585T
M2, M2#2, M2#3, M2#4: MountingHole_2.2mm_M2
Q1: PT334; LED_D5.0mm_Horizontal_O1.27mm_Z3.0mm_Clear
Q2: BC337; TO92254P480H870-3
R1, R2, R7: 100kΩ; R_Axial_DIN0207_L6.3mm_D2.5mm_P10.16mm_Horizontal
R3, R5: 10kΩ; R_Axial_DIN0207_L6.3mm_D2.5mm_P10.16mm_Horizontal
R4: 1MΩ; R_Axial_DIN0207_L6.3mm_D2.5mm_P10.16mm_Horizontal
R6: 1kΩ; R_Axial_DIN0207_L6.3mm_D2.5mm_P10.16mm_Horizontal
R8: 47kΩ; R_Axial_DIN0207_L6.3mm_D2.5mm_P10.16mm_Horizontal
SW2: SW_DIP_x05; SW_DIP_SPSTx05_Slide_9.78x14.88mm_W7.62mm_P2.54mm
TP4056 w/ Step Up: SolderWire-0.5sqmm_1x03_P4.6mm_D0.9mm_OD2.1mm
U1: LM393N; DIP254P762X508-8

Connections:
+3V3: .19, C1.1, R2.2, R3.2, R5.2, SW2.6, SW2.7, SW2.8, SW2.9, SW2.10, U1.8
+5V In PCB: .1, LD1.1 (K), LS1.P, TP4056 w/ Step Up.2
GND: .6, #2.13, #2.19, C1.2, C2.2, LD1.2 (A), Q1.2 (E), Q2.3 (E), R1.2, R8.2, TP4056 w/ Step Up.3, U1.4
unnamed: C2.1, Q1.1 (C), R3.1, R4.2, U1.3
unnamed: Q2.2 (B), R6.1
unnamed: LS1.N, Q2.1 (C)
unnamed: #2.14, R4.1, R5.1, U1.1
unnamed: #2.12, R6.2
unnamed: R7.1, TP4056 w/ Step Up.1
unnamed: .14, R7.2, R8.1
unnamed: #2.17, SW2.1
unnamed: #2.18, SW2.2
unnamed: .11, SW2.3
unnamed: .10, SW2.4
unnamed: .9, SW2.5
unnamed: R1.1, R2.1, U1.2

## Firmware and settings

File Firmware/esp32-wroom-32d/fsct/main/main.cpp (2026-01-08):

#include <stdio.h>
#include "esp_log.h"
#include "adc/battery_adc.hpp"
#include "gpio/gpiostartup.hpp"
#include "gatt/gattstartup.hpp"
#include "nvs_flash.h"
#include "driver/gpio.h"
#include "freertos/FreeRTOS.h"
#include "freertos/queue.h"
#include "freertos/task.h"
#include "esp_timer.h"

#include "status/fsct_status.hpp"

namespace {
constexpr gpio_num_t kBeamGpio = GPIO_NUM_21;
constexpr char kBeamTag[] = "BeamDemo";

QueueHandle_t s_beam_event_queue = nullptr;
volatile TickType_t s_last_isr_tick = 0;

void IRAM_ATTR beam_gpio_isr_handler(void* arg) {
    const TickType_t now_tick = xTaskGetTickCountFromISR();
    const TickType_t last_tick = s_last_isr_tick;

    // Simple chatter guard (LM393 / wiring can bounce a bit)
    if ((now_tick - last_tick) < pdMS_TO_TICKS(20)) {
        return;
    }
    s_last_isr_tick = now_tick;

    const uint32_t gpio_num = static_cast<uint32_t>(reinterpret_cast<uintptr_t>(arg));
    BaseType_t higher_prio_woken = pdFALSE;
    (void)xQueueSendFromISR(s_beam_event_queue, &gpio_num, &higher_prio_woken);
    if (higher_prio_woken == pdTRUE) {
        portYIELD_FROM_ISR();
    }
}

void beam_event_task(void* /*arg*/) {
    int last_level = gpio_get_level(kBeamGpio);
    ESP_LOGI(kBeamTag, "Initial: %s (level=%d)", last_level ? "BEAM BROKEN" : "beam intact", last_level);

    // Publish initial beam status for GATT consumers.
    FSCT::fsct_status_set_beam(last_level != 0, static_cast<uint64_t>(esp_timer_get_time() / 1000));

    while (true) {
        uint32_t gpio_num = 0;
        if (xQueueReceive(s_beam_event_queue, &gpio_num, portMAX_DELAY) != pdTRUE) {
            continue;
        }
        if (gpio_num != static_cast<uint32_t>(kBeamGpio)) {
            continue;
        }

        const int level = gpio_get_level(kBeamGpio);
        if (level == last_level) {
            continue;
        }
        last_level = level;

        // Per gpio_startup(): Low = beam intact, High = beam broken
        ESP_LOGI(kBeamTag, "%s", level ? "BEAM BROKEN" : "beam restored");

        FSCT::fsct_status_set_beam(level != 0, static_cast<uint64_t>(esp_timer_get_time() / 1000));

        // Beep the buzzer briefly on beam break/restored
        gpio_set_level(GPIO_NUM_19, 1); // Buzzer ON
        vTaskDelay(50 / portTICK_PERIOD_MS);
        gpio_set_level(GPIO_NUM_19, 0); // Buzzer OFF

    }

}

void battery_status_task(void* /*arg*/) {
    while (true) {
        int battery_mv = -1;
        int battery_percent = -1;

        esp_err_t mv_err = battery_adc_read_battery_mv(&battery_mv);
        if (mv_err != ESP_OK) {
            ESP_LOGW("FSCTBattery", "battery_adc_read_battery_mv failed: %s", esp_err_to_name(mv_err));
            battery_mv = -1;
        }

        esp_err_t pct_err = battery_adc_read_percent(&battery_percent);
        if (pct_err != ESP_OK) {
            ESP_LOGW("FSCTBattery", "battery_adc_read_percent failed: %s", esp_err_to_name(pct_err));
            battery_percent = -1;
        }

        FSCT::fsct_status_set_battery(
            battery_mv,
            battery_percent,
            static_cast<uint64_t>(esp_timer_get_time() / 1000));

        vTaskDelay(pdMS_TO_TICKS(5000));
    }
}

void start_beam_demo() {
    if (s_beam_event_queue != nullptr) {
        return;
    }

    s_beam_event_queue = xQueueCreate(16, sizeof(uint32_t));
    if (s_beam_event_queue == nullptr) {
        ESP_LOGE(kBeamTag, "Failed to create event queue");
        return;
    }

    // ISR service is installed in gpio_startup(); we only add the handler here.
    esp_err_t err = gpio_isr_handler_add(
        kBeamGpio,
        beam_gpio_isr_handler,
        reinterpret_cast<void*>(static_cast<uintptr_t>(kBeamGpio)));
    if (err != ESP_OK) {
        ESP_LOGE(kBeamTag, "gpio_isr_handler_add failed: %s", esp_err_to_name(err));
        return;
    }

    xTaskCreate(beam_event_task, "beam_event", 4096, nullptr, 10, nullptr);
    ESP_LOGI(kBeamTag, "Beam-break demo active on GPIO %d", static_cast<int>(kBeamGpio));
}
} // namespace

extern "C" void app_main(void) {
    // NVS initialization for ESP-NOW
    esp_err_t ret = nvs_flash_init();
    if (ret == ESP_ERR_NVS_NO_FREE_PAGES || ret == ESP_ERR_NVS_NEW_VERSION_FOUND) {
        ESP_ERROR_CHECK(nvs_flash_erase());
        ESP_ERROR_CHECK(nvs_flash_init());
    } else {
        ESP_ERROR_CHECK(ret);
    }

    // GPIO initialization needs to take place before GATT initialization so
    // that any GPIO-based configuration settings are available to GATT.
    gpio_startup();

    // Beam-break interrupt demo (GPIO21). Logs "BEAM BROKEN" / "beam restored".
    start_beam_demo();

    // Battery ADC initialization (ADC1 CH7 / GPIO35)
    ESP_ERROR_CHECK(battery_adc_init());

    ESP_LOGI("FSCTMain", "FSCT Position: %d", fsct_gpio_position);
    ESP_LOGI("FSCTMain", "FSCT Group: %d", fsct_gpio_group);

    // Initialize the BLE stack and GATT services
    initialize_nimble();

    // Diagnostic Log
    ESP_LOGI("FSCTMain", "Nimble initialized");
    printf("Hello from FSCT Timer!\n");

    // Battery status cache refresh (for GATT diag reads)
    xTaskCreate(battery_status_task, "battery_status", 4096, nullptr, 8, nullptr);

    // Beep the piezo three times
    for(int i = 0; i < 3; i++) {
        ESP_LOGI("FSCTMain", "Beep %d", i+1);
        gpio_set_level(GPIO_NUM_19, 1); // Buzzer ON
        vTaskDelay(50 / portTICK_PERIOD_MS);
        gpio_set_level(GPIO_NUM_19, 0); // Buzzer OFF
        vTaskDelay(50 / portTICK_PERIOD_MS);
    }
}

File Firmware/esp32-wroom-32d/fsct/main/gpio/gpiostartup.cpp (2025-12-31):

#include <stdio.h>
#include <string.h>
#include <stdlib.h>
#include <inttypes.h>
#include "driver/gpio.h"

int fsct_gpio_position = -1;
int fsct_gpio_group = -1;
bool fsct_gpio_bringup_complete = false;

void configure_gpios() {
    gpio_config_t io_conf = {};

    //// --- Group 1: Configuration GPIOs ---
    // 22 / 23 dip input for sheet position
    // 25 / 26 / 27 dip input for sheet/group number
    io_conf.intr_type = GPIO_INTR_DISABLE;
    io_conf.pin_bit_mask = 
        (1ULL << GPIO_NUM_22) | 
        (1ULL << GPIO_NUM_23) | 
        (1ULL << GPIO_NUM_25) | 
        (1ULL << GPIO_NUM_26) | 
        (1ULL << GPIO_NUM_27);
    io_conf.mode = GPIO_MODE_INPUT;
    io_conf.pull_up_en = GPIO_PULLUP_DISABLE;
    io_conf.pull_down_en = GPIO_PULLDOWN_ENABLE;
    gpio_config(&io_conf);

    //// --- Group 2: Interrupt GPIOs ---
    // GPIO 21: Beam break sensor (LM393)
    // Low = Beam intact, High = beam broken
    // We trigger on both rising and falling edges to be able to
    // detect both beam breaks and beam restores.
    io_conf.intr_type = GPIO_INTR_ANYEDGE;
    io_conf.pin_bit_mask = (1ULL << GPIO_NUM_21);
    io_conf.mode = GPIO_MODE_INPUT;
    // LM393 is open-collector; enable pull-up to ensure High state when beam is broken 
    io_conf.pull_up_en = GPIO_PULLUP_DISABLE;
    io_conf.pull_down_en = GPIO_PULLDOWN_DISABLE;
    gpio_config(&io_conf);

    // Install ISR service
    // NOTE for downstream services... to distinguish between beam broken
    // and beam restored, read the GPIO level at interrupt time. `gpio_get_level(GPIO_NUM_21)`
    // will return 1 if beam is broken, 0 if beam is intact.
    gpio_install_isr_service(0);
    
    //// --- Group 3: Output GPIOs ---
    // GPIO 19: Buzzer drive (NPN transistor base drive via resistor)
    io_conf.intr_type = GPIO_INTR_DISABLE;
    io_conf.pin_bit_mask = (1ULL << GPIO_NUM_19);
    io_conf.mode = GPIO_MODE_OUTPUT;
    io_conf.pull_up_en = GPIO_PULLUP_DISABLE;
    io_conf.pull_down_en = GPIO_PULLDOWN_DISABLE;
    gpio_config(&io_conf);

    // Default OFF (don't need the **** buzzer on startup)
    gpio_set_level(GPIO_NUM_19, 0);
}

void set_fsct_gpio_variables() {
    // Read position from GPIOs 22 and 23
    int pos_bit0 = gpio_get_level(GPIO_NUM_22);
    int pos_bit1 = gpio_get_level(GPIO_NUM_23);
    fsct_gpio_position = (pos_bit1 << 1) | pos_bit0;

    // Read group from GPIOs 25, 26, and 27
    int group_bit0 = gpio_get_level(GPIO_NUM_25);
    int group_bit1 = gpio_get_level(GPIO_NUM_26);
    int group_bit2 = gpio_get_level(GPIO_NUM_27);
    fsct_gpio_group = (group_bit2 << 2) | (group_bit1 << 1) | group_bit0;
}

void gpio_startup() {
    configure_gpios();

    // We only need to read the configuration GPIOs once at startup
    // to set the position and group variables. If a user wants to
    // change these values, they must power cycle the device.
    set_fsct_gpio_variables();
    
    // error handling should be added here
    fsct_gpio_bringup_complete = true;
}

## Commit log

2025-12-17 more design considerations and an initial pass at stone sequence... testing out KiCad as PCB and schematic design solution
    [MainBoard.kicad_pcb, MainBoard.kicad_sch]
2025-12-21 Refactor README and add user journey documentation for curling timer system
    - Updated GATT service model section in README to emphasize structured data exchange and real-time updates.
    - Created a semi-comprehensive user journey document detailing preconfiguration, setup, operation, and maintenance processes for the curling timer system.
    [MainBoard.kicad_sch]
2025-12-21 Update BOM.md with corrected links for LM393 Comparator and other components
2025-12-21 Update LAST UPDATED date in BOM.md to reflect the latest revision
2025-12-21 (CO-PILOT) Initialize web application with Bluetooth functionality.
    - Added package.json for project configuration and dependencies.
    - Implemented main.ts for handling Bluetooth device connections and UI interactions.
    - Created style.css for basic styling of the application.
    - Configured TypeScript with tsconfig.json for strict type checking and module resolution.
    - Set up Vite configuration in vite.config.ts for building and serving the application.
2025-12-23 - Implemented Framework for Mobile App - Created Wishlist (Added Apple WatchOS and Garmin Connect IQ App)
2025-12-29 Iniital schematic (poor layout), and added additional functionality to the firmware
    [MainBoard.kicad_sch]
2025-12-30 Lots of changes - initial pcb layout without wires
    [MainBoard.kicad_pcb, MainBoard.kicad_sch]
2025-12-30 PCB v1.0 - schematic needs review still in comparison to PCB - initial order of PCBs with JLCPCB. Updated BOM to reflect actual resistor/capacitor count.
    [MainBoard-B_Cu.gbl, MainBoard-B_Mask.gbs, MainBoard-B_Paste.gbp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]
2025-12-31 Ran into issues in breadboarding - hoping r2 of PCB fixes. Luckily caught the order in time to get new files uploaded so order was not wasted.
    [MainBoard-B_Cu.gbl, MainBoard-B_Mask.gbs, MainBoard-B_Paste.gbp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]
2025-12-31 Gerber files probably need to be updated again (apparently dimensions were on the copper layer - did not cause grief with JLCPCB). BOM updated with OSHPark quote.
    [MainBoard.kicad_pcb]
2026-01-06 First PCBs are in - and they test well... putting test enclosure together now test fit and function.
    [Curling Timer v1 - Test 2.3mf, Curling Timer v1 - Test.3mf]
2026-01-08 Add some test iterations of the enclosure, and add a basic test to the firmware (beep on change of beam state)
    [Curling Timer v1 - Test 3.3mf, Curling Timer v1 - Test 4.3mf, Curling Timer v1 - Test 5.3mf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]
2026-01-10 Update design decisions for laser alignment
    Added recommendation to improve laser alignment stability.
2026-01-24 A lot more tests - but believe I've landed on a prototype. Will test more at the club
    [Curling Timer v1 - Main Body - Test 10.3mf, Curling Timer v1 - Main Body - Test 8.3mf, Curling Timer v1 - Main Body - Test 9.3mf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]
2026-01-27 Well, developing for Garmin is easier than imagined... going to start with it since I've got myself a Garmin watch...
    [Reflector Mount Base.3mf]
